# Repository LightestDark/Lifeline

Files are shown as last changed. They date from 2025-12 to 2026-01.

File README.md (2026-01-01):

# Lifeline

This project aims to expand on the existing LoRa Puck guide, to make a pair of fully functioning transmitters that can display messages from the latter via oled, provide accurate GPS location up to 2 meters and even vital info on moisture, temperature and pressure to make an esitmated guess on the weather at the area and relay it.

# Lessons

I LOVED the physics behind the why in the routing it actually linked so well to my own studies, especially the low pass filtering. Despite this being my smallest pcb to date by no means was it the easiest, with cramming as efficiently each component so there was enough room as well as keeping enough space to allow the RF components to work properly and juggle vias everywhere it was a labour.

# Assembly

Made a simple box with plently space for antennas and display







# PCB

Ensured short efficient tracks by precise placing of components





# Schematic

Added GPS, OLED and An array of sesnors packed into a BME280



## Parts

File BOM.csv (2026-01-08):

Index | LCSC# | MPN | Manufacturer | Package | Description | RoHS | Quantity | MOQ | Multiple | Unit Price($) | Extended Price($) | Product Link | Total Price ($)
1 | C92361 | CL05A474KA5NNNC | Samsung Electro-Mechanics | 402 | 25V 470nF X5R ±10% 0402 Ceramic Capacitors RoHS | yes | 10 | 10 | 10 | 0.0118 | 0.12 | https://www.lcsc.com/product-detail/C92361.html | 1.12
2 | C1525 | CL05B104KO5NNNC | Samsung Electro-Mechanics | 402 | 16V 100nF X7R ±10% 0402 Ceramic Capacitors RoHS | yes | 100 | 100 | 100 | 0.0012 | 0.12 | https://www.lcsc.com/product-detail/C1525.html | 1.24
3 | C1864241 | GJM1555C1H390GB01D | muRata | 402 | 50V 39pF C0G ±2% 0402 Ceramic Capacitors RoHS | yes | 20 | 20 | 20 | 0.0355 | 0.71 | https://www.lcsc.com/product-detail/C1864241.html | 1.95
4 | C76906 | GJM1555C1H3R3BB01D | muRata | 402 | 50V 3.3pF C0G 0402 Ceramic Capacitors RoHS | yes | 50 | 50 | 50 | 0.0166 | 0.83 | https://www.lcsc.com/product-detail/C76906.html | 1.78
5 | C77018 | GRM155R71H102KA01D | muRata | 402 | 50V 1nF X7R ±10% 0402 Ceramic Capacitors RoHS | yes | 100 | 100 | 100 | 0.002 | 0.2 | https://www.lcsc.com/product-detail/C77018.html | 1.98
6 | C76970 | GRM1555C1H470JA01D | muRata | 402 | 50V 47pF C0G ±5% 0402 Ceramic Capacitors RoHS | yes | 100 | 100 | 100 | 0.0022 | 0.22 | https://www.lcsc.com/product-detail/C76970.html | 2.2
7 | C307339 | CL05B473KB5VPNC | Samsung Electro-Mechanics | 402 | 50V 47nF X7R ±10% 0402 Ceramic Capacitors RoHS | yes | 100 | 100 | 100 | 0.0076 | 0.76 | https://www.lcsc.com/product-detail/C307339.html | 2.96
8 | C14445 | CL05A105KP5NNNC | Samsung Electro-Mechanics | 402 | 10V 1uF X5R ±10% 0402 Ceramic Capacitors RoHS | yes | 100 | 100 | 100 | 0.0017 | 0.17 | https://www.lcsc.com/product-detail/C14445.html | 4.13
9 | C76950 | GRM1555C1H150JA01D | muRata | 402 | 50V 15pF C0G ±5% 0402 Ceramic Capacitors RoHS | yes | 100 | 100 | 100 | 0.0025 | 0.25 | https://www.lcsc.com/product-detail/C76950.html | 4.38
10 | C315248 | CL05A106MP5NUNC | Samsung Electro-Mechanics | 402 | 10V 10uF X5R ±20% 0402 Ceramic Capacitors RoHS | yes | 20 | 20 | 20 | 0.0085 | 0.17 | https://www.lcsc.com/product-detail/C315248.html | 3.55
11 | C85815 | BLM15AX102SN1D | muRata | 402 | 490mΩ ±25% 1kΩ@100MHz 0402 Ferrite Beads and Chips RoHS | yes | 100 | 100 | 100 | 0.0055 | 0.55 | https://www.lcsc.com/product-detail/C85815.html | 4.1
12 | C5224443 | 0900FM15K0039E | Johanson Dielectrics | SMD-10P,1.2x2mm | SMD-10P,1.2x2mm Ceramic Filters RoHS | yes | 2 | 1 | 1 | 1.8851 | 3.77 | https://www.lcsc.com/product-detail/C5224443.html | 7.87
13 | C3025063 | USB4105-GF-A-060 | Global Connector Technology | SMD | SMD USB, DVI, HDMI Connector Assemblies RoHS | yes | 2 | 1 | 1 | 1.0013 | 2 | https://www.lcsc.com/product-detail/C3025063.html | 9.87
14 | C3221788 | LQW15DN150M00D | muRata | 402 | 15uH 100mA 0402 Fixed Inductors RoHS | yes | 2 | 1 | 1 | 1.1864 | 2.37 | https://www.lcsc.com/product-detail/C3221788.html | 12.24
15 | C337956 | LQW15AN9N1H00D | muRata | 402 | 9.1nH Unshielded Inductor 0402 Fixed Inductors RoHS | yes | 10 | 10 | 10 | 0.0388 | 0.39 | https://www.lcsc.com/product-detail/C337956.html | 12.63
16 | C22334 | LQW15AN47NG00D | muRata | 402 | 47nH Unshielded Inductor 0402 Fixed Inductors RoHS | yes | 20 | 20 | 20 | 0.0365 | 0.73 | https://www.lcsc.com/product-detail/C22334.html | 13.36
17 | C413063 | ERJ2RKF1000X | PANASONIC | 402 | 100mW 100Ω ±100ppm/℃ Thick Film Resistor ±1% 0402 Chip Resistor - Surface Mount RoHS | yes | 100 | 100 | 100 | 0.0047 | 0.47 | https://www.lcsc.com/product-detail/C413063.html | 13.83
18 | C191123 | ERJ2RKF1002X | PANASONIC | 402 | 100mW 10kΩ 50V ±100ppm/℃ Thick Film Resistor ±1% 0402 Chip Resistor - Surface Mount RoHS | yes | 100 | 100 | 100 | 0.0045 | 0.45 | https://www.lcsc.com/product-detail/C191123.html | 14.28
19 | C2076786 | ERJ2RKF27R4X | PANASONIC | 402 | 100mW 27.4Ω 50V ±100ppm/℃ Thick Film Resistor ±1% 0402 Chip Resistor - Surface Mount RoHS | yes | 50 | 50 | 50 | 0.0057 | 0.29 | https://www.lcsc.com/product-detail/C2076786.html | 14.57
20 | C242161 | ERJ2RKF1001X | PANASONIC | 402 | 100mW 1kΩ ±100ppm/℃ Thick Film Resistor ±1% 0402 Chip Resistor - Surface Mount RoHS | yes | 100 | 100 | 100 | 0.0049 | 0.49 | https://www.lcsc.com/product-detail/C242161.html | 15.06
21 | C105872 | RC0402FR-075K1L | YAGEO | 402 | 5.1kΩ 62.5mW 50V ±100ppm/℃ Thick Film Resistor ±1% 0402 Chip Resistor - Surface Mount RoHS | yes | 100 | 100 | 100 | 0.0007 | 0.07 | https://www.lcsc.com/product-detail/C105872.html | 15.13
22 | C2689642 | PTS636SK25SMTRLFS | C&K | SMD,6x3.5mm | 12V Rectangular Button SPST-NO 50mA SMD,6x3.5mm Tactile Switches RoHS | yes | 5 | 5 | 5 | 0.3601 | 1.8 | https://www.lcsc.com/product-detail/C2689642.html | 16.93
23 | C191341 | SX1262IMLTRT | SEMTECH | QFN-24-EP(4x4) | 300Kbps General Purpose ISM <1 GHz SPI -148dBm 150MHz~960MHz QFN-24-EP(4x4) RF Transceiver ICs RoHS | yes | 1 | 1 | 1 | 3.1633 | 3.16 | https://www.lcsc.com/product-detail/C191341.html | 20.09
24 | C2040 | RP2040 | Raspberry Pi | LQFN-56(7x7) | 133MHz 30 LQFN-56(7x7) Microcontrollers RoHS | yes | 1 | 1 | 1 | 0.9482 | 0.95 | https://www.lcsc.com/product-detail/C2040.html | 21.04
25 | C97521 | W25Q128JVSIQ | Winbond | SOIC-8-208mil | 128Mbit 2.7V~3.6V 133MHz SPI SOIC-8-208mil Memory (ICs) RoHS | yes | 1 | 1 | 1 | 1.8032 | 1.8 | https://www.lcsc.com/product-detail/C97521.html | 22.84
26 | C51118 | AP2112K-3.3TRG1 | DIODES | SOT-25-5 | 65dB@(1kHz) Positive Fixed 3.3V SOT-25-5 Voltage Regulators - Linear, Low Drop Out (LDO) Regulators RoHS | yes | 5 | 5 | 5 | 0.1344 | 0.67 | https://www.lcsc.com/product-detail/C51118.html | 23.51
27 | C470892 | PE4259-63 | pSemi | SC-70-6 | 30dB 0.35dB SC-70-6 RF Switches RoHS | yes | 1 | 1 | 1 | 0.5777 | 0.58 | https://www.lcsc.com/product-detail/C470892.html | 24.09
28 | C276421 | ABM8G-12.000MHZ-B4Y-T | ABRACON | SMD3225-4P | 10pF SMD3225-4P Crystals RoHS | yes | 2 | 1 | 1 | 0.454 | 0.91 | https://www.lcsc.com/product-detail/C276421.html | 25
29 | C5187559 | ABM8G-32.000MHZ-B4Y-T | ABRACON | SMD3225-4P | SMD3225-4P Crystals RoHS | yes | 2 | 1 | 1 | 0.7108 | 1.42 | https://www.lcsc.com/product-detail/C5187559.html | 26.42
30 | N/A | Shipping global direct |  |  |  |  |  |  |  |  | 9.13 |  | 35.55
31 | N/A | JLCPCB excl shipping |  |  | green+stencil |  |  |  |  |  | 14.08 |  | 49.63
32 |  | Shipping europacket bc cheaper than standard direct |  |  | 1 eur cheaper approx |  |  |  |  |  | 24.36 |  | 69.99
33 |  | 4pin Headers |  |  |  |  |  |  |  |  |  |  | 4
33 |  | 3D printing form printing legion delivery |  |  | Royal Mail |  |  |  |  |  | 10.00
34 |  | Customs |  |  |  |  |  |  |  |  | 8.3 |  | TOTAL: 97.40

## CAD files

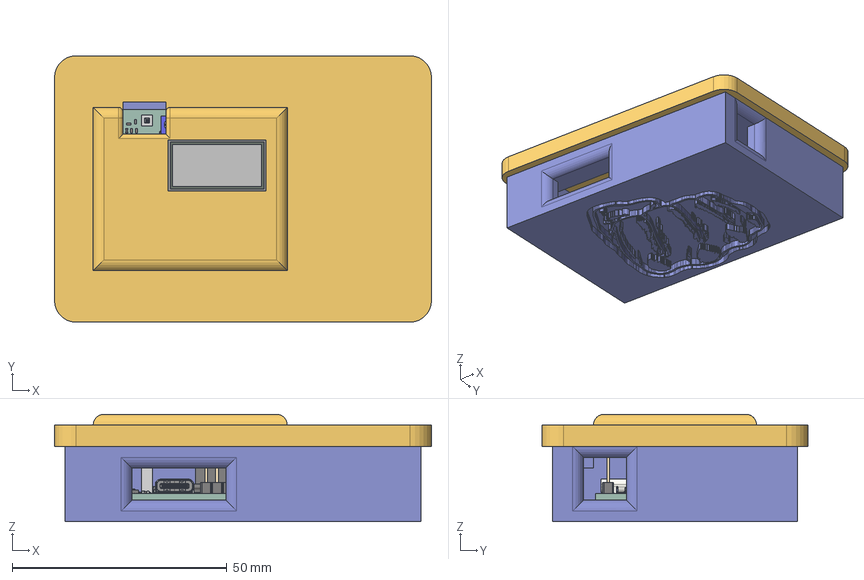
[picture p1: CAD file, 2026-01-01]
Lifeline.step
87.7 x 62.0 x 25.0 mm
C_0402_1005Metric x 25
PinSocket_1x01_P2.54mm_Vertical
QFN-56-1EP_7x7mm_P0.4mm_EP3.2x3.2mm
R_0402_1005Metric x 8
SOIC-8_5.3x5.3mm_P1.27mm
lorapuck 1.9.1
lorapuck 1.9.2
lorapuck 1.9.3
SW_Tactile_SPST_NO_Straight_CK_PTS636Sx25SMTRLFS x 2
QFN-24-1EP_4x4mm_P0.5mm_EP2.6x2.6mm
Crystal_SMD_Abracon_ABM8G-4Pin_3.2x2.5mm
PinSocket_1x04_P2.54mm_Vertical
SOT-363_SC-70-6
L_0402_1005Metric x 4
PinHeader_1x04_P2.54mm_Vertical x 2
USB_C_Receptacle_GCT_USB4105-xx-A_16P_TopMnt_Horizontal
SOT-23-5
Crystal_SMD_3225-4Pin_3.2x2.5mm
lorapuck_PCB
DM-OLED096-636_Panel
DM-OLED096-636_Module

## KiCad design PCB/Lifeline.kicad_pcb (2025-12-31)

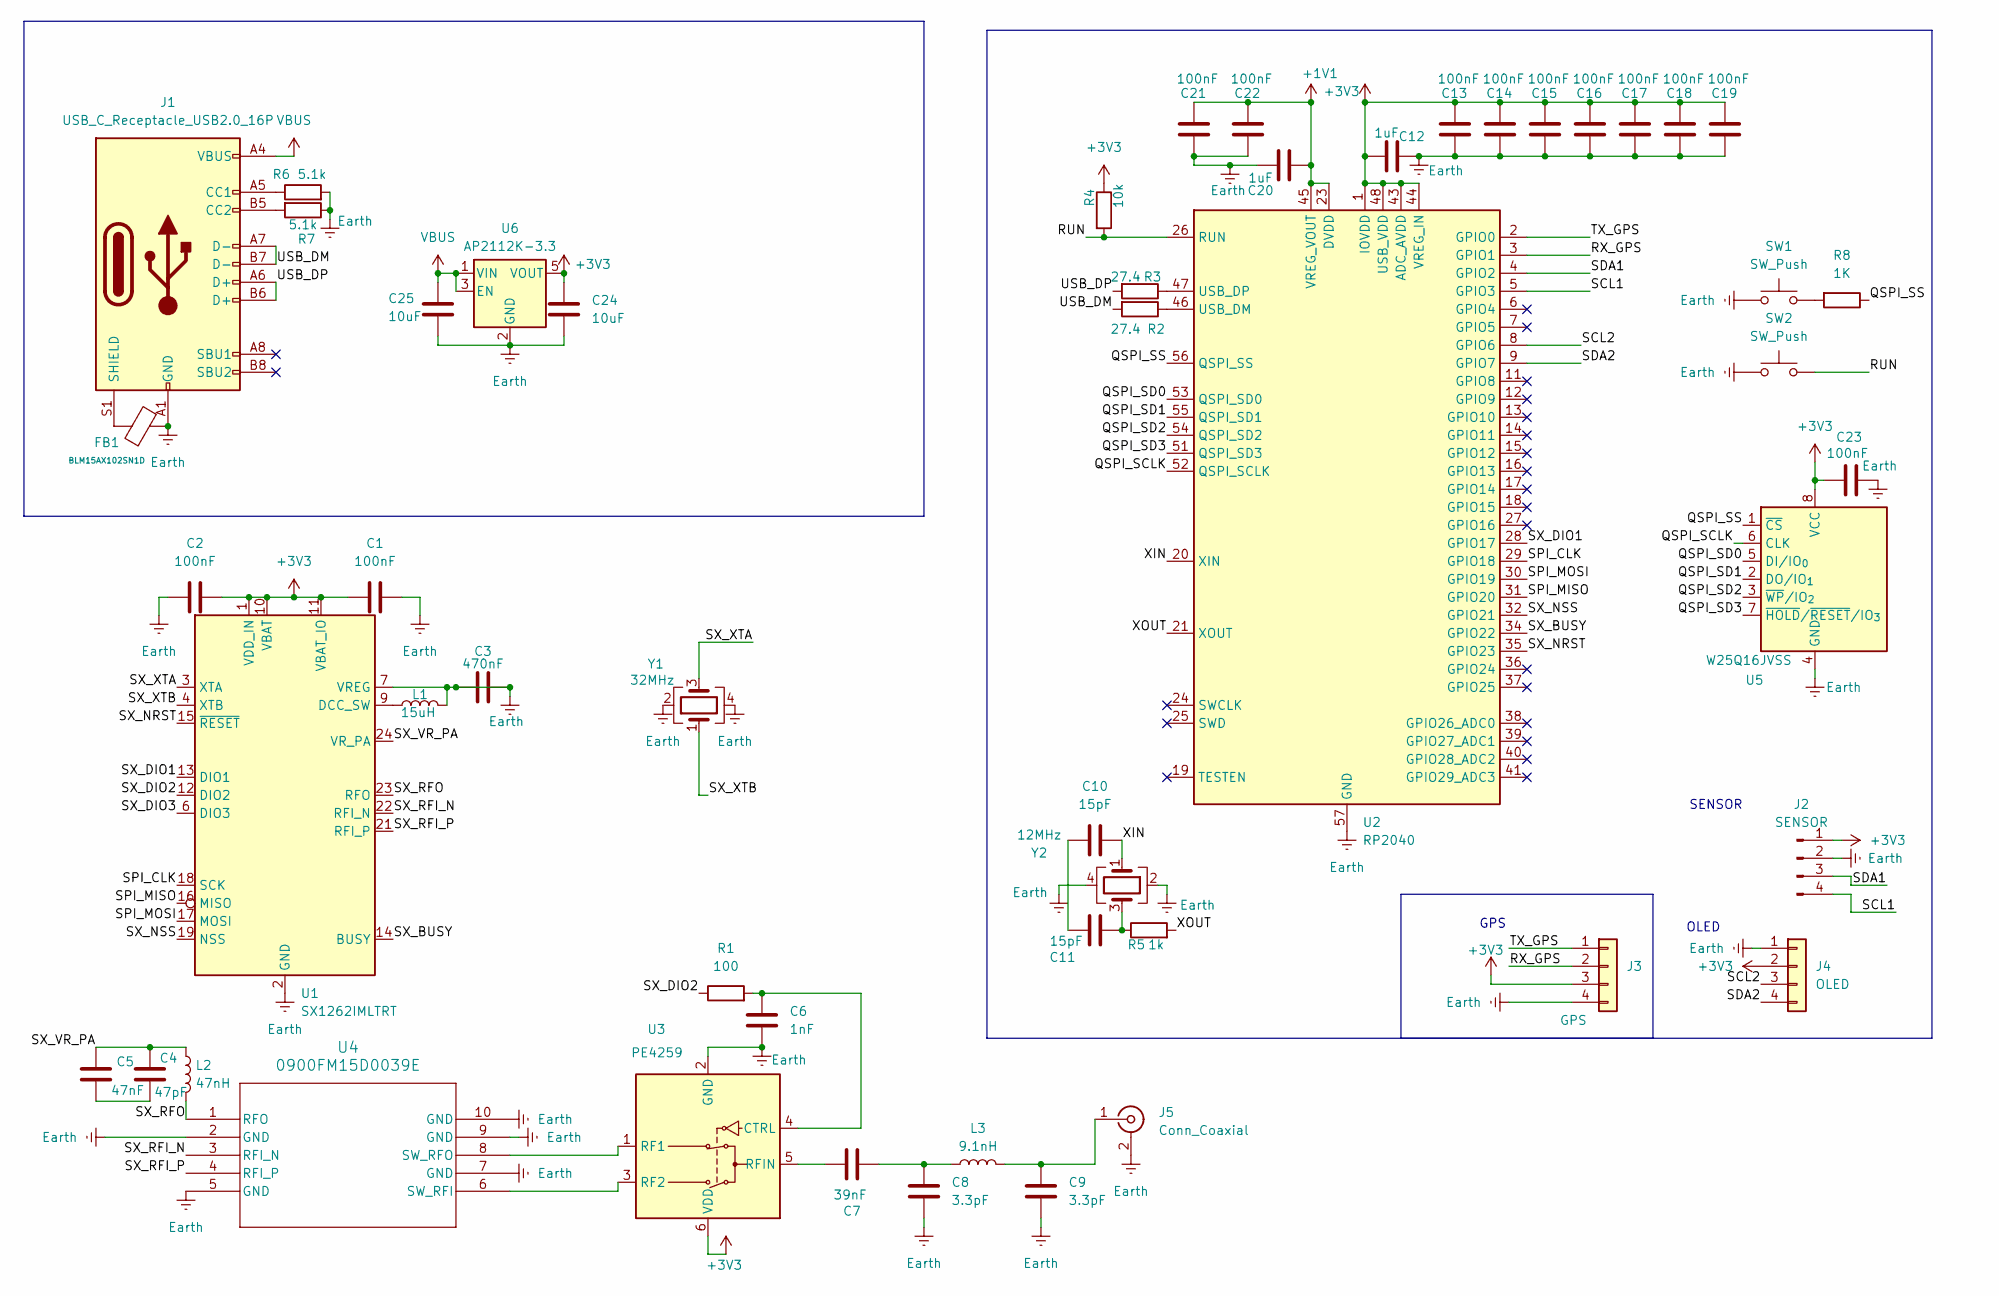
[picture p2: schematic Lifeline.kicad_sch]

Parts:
C1, C2, C13, C14, C15, C16, C17, C18, C19, C21, C22, C23: 100nF; C_0402_1005Metric
C3: 470nF; C_0402_1005Metric
C4: 47pF; C_0402_1005Metric
C5: 47nF; C_0402_1005Metric
C6: 1nF; C_0402_1005Metric
C7: 39nF; C_0402_1005Metric
C8, C9: 3.3pF; C_0402_1005Metric
C10, C11: 15pF; C_0402_1005Metric
C12, C20: 1uF; C_0402_1005Metric
C24, C25: 10uF; C_0402_1005Metric
FB1: BLM15AX102SN1D; L_0402_1005Metric; Current Rating 2A; Tolerance ±25%; Part BLM18PG121SN1D; LCSC C14709
J1: USB_C_Receptacle_USB2.0_16P; USB_C_Receptacle_GCT_USB4105-xx-A_16P_TopMnt_Horizontal
J2: SENSOR; PinHeader_1x04_P2.54mm_Vertical
J3: GPS; PinHeader_1x04_P2.54mm_Vertical
J4: OLED; PinSocket_1x04_P2.54mm_Vertical
J5: Conn_Coaxial; U.FL_Hirose_U.FL-R-SMT-1_Vertical
L1: 15uH; L_0402_1005Metric
L2: 47nH; L_0402_1005Metric
L3: 9.1nH; L_0402_1005Metric
R1: 100; R_0402_1005Metric
R2, R3: 27.4; R_0402_1005Metric
R4: 10k; R_0402_1005Metric
R5: 1k; R_0402_1005Metric
R6, R7: 5.1k; R_0402_1005Metric
R8: 1K; R_0402_1005Metric
SW1, SW2: SW_Push; SW_Tactile_SPST_NO_Straight_CK_PTS636Sx25SMTRLFS
U1: SX1262IMLTRT; QFN-24-1EP_4x4mm_P0.5mm_EP2.6x2.6mm
U2: RP2040; QFN-56-1EP_7x7mm_P0.4mm_EP3.2x3.2mm
U3: PE4259; SOT-363_SC-70-6
U4: 0900FM15D0039E; Balun_Johanson_0900FM15K0039
U5: W25Q16JVSS; SOIC-8_5.3x5.3mm_P1.27mm
U6: AP2112K-3.3; SOT-23-5
Y1: 32MHz; Crystal_SMD_3225-4Pin_3.2x2.5mm
Y2: 12MHz; Crystal_SMD_Abracon_ABM8G-4Pin_3.2x2.5mm

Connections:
+1V1: C20.2, C21.1, C22.1, U2.23 (DVDD), U2.45 (VREG_VOUT), U2.50 (DVDD)
+3V3: C1.1, C2.2, C12.1, C13.1, C14.1, C15.1, C16.1, C17.1, C18.1, C19.1, C23.1, C24.1, J2.1, J3.3, J4.2, R4.1, U1.1 (VDD_IN), U1.10 (VBAT), U1.11 (VBAT_IO), U2.1 (IOVDD), U2.10 (IOVDD), U2.22 (IOVDD), U2.33 (IOVDD), U2.42 (IOVDD), U2.43 (ADC_AVDD), U2.44 (VREG_IN), U2.48 (USB_VDD), U2.49 (IOVDD), U3.6 (VDD), U5.8 (VCC), U6.5 (VOUT)
/QSPI_SCLK: U2.52 (QSPI_SCLK), U5.6 (CLK)
/QSPI_SD0: U2.53 (QSPI_SD0), U5.5 (DI/IO_{0})
/QSPI_SD1: U2.55 (QSPI_SD1), U5.2 (DO/IO_{1})
/QSPI_SD2: U2.54 (QSPI_SD2), U5.3 (~WP/IO_{2})
/QSPI_SD3: U2.51 (QSPI_SD3), U5.7 (~HOLD/~RESET/IO_{3})
/QSPI_SS: R8.1, U2.56 (QSPI_SS), U5.1 (~CS)
/RUN: R4.2, SW2.2, U2.26 (RUN)
/RX_GPS: J3.2, U2.3 (GPIO1)
/SCL1: J2.4, U2.5 (GPIO3)
/SCL2: J4.3, U2.8 (GPIO6)
/SDA1: J2.3, U2.4 (GPIO2)
/SDA2: J4.4, U2.9 (GPIO7)
/SPI_CLK: U1.18 (SCK), U2.29 (GPIO18)
/SPI_MISO: U1.16 (MISO), U2.31 (GPIO20)
/SPI_MOSI: U1.17 (MOSI), U2.30 (GPIO19)
/SX_BUSY: U1.14 (BUSY), U2.34 (GPIO22)
/SX_DIO1: U1.13 (DIO1), U2.28 (GPIO17)
/SX_DIO2: R1.1, U1.12 (DIO2)
/SX_DIO3: U1.6 (DIO3)
/SX_NRST: U1.15 (~RESET), U2.35 (GPIO23)
/SX_NSS: U1.19 (NSS), U2.32 (GPIO21)
/SX_RFI_N: U1.22 (RFI_N), U4.3 (RFI_N)
/SX_RFI_P: U1.21 (RFI_P), U4.4 (RFI_P)
/SX_RFO: L2.2, U1.23 (RFO), U4.1 (RFO)
/SX_VR_PA: C4.1, C5.1, L2.1, U1.24 (VR_PA)
/SX_XTA: U1.3 (XTA), Y1.3
/SX_XTB: U1.4 (XTB), Y1.1
/TX_GPS: J3.1, U2.2 (GPIO0)
/USB_DM: J1.A7 (D-), J1.B7 (D-), R2.2
/USB_DP: J1.A6 (D+), J1.B6 (D+), R3.2
/XIN: C10.2, U2.20 (XIN), Y2.1
/XOUT: R5.2, U2.21 (XOUT)
Earth: C1.2, C2.1, C3.1, C3.2, C6.2, C8.2, C9.2, C12.2, C13.2, C14.2, C15.2, C16.2, C17.2, C18.2, C19.2, C20.1, C21.2, C22.2, C23.2, C24.2, C25.2, FB1.2, J1.A1 (GND), J1.A12 (GND), J1.B1 (GND), J1.B12 (GND), J2.2, J3.4, J4.1, J5.2 (Ext), L1.2, R6.2, R7.1, SW1.1, SW2.1, U1.2 (GND), U1.5 (GND), U1.7 (VREG), U1.8 (GND), U1.20 (GND), U1.25 (GND), U2.57 (GND), U3.2 (GND), U4.2 (GND), U4.5 (GND), U4.7 (GND), U4.9 (GND), U4.10 (GND), U5.4 (GND), U6.2 (GND), Y1.2, Y1.4, Y2.2, Y2.4
unnamed: C4.2, C5.2
unnamed: C7.2, C8.1, L3.1
unnamed: C10.1, C11.1
unnamed: C11.2, R5.1, Y2.3
unnamed: J1.A5 (CC1), R6.1
unnamed: J1.B5 (CC2), R7.2
unnamed: FB1.1, J1.S1 (SHIELD)
unnamed: C9.1, J5.1 (In), L3.2
unnamed: R8.2, SW1.2
unnamed: L1.1, U1.9 (DCC_SW)
unnamed: R2.1, U2.46 (USB_DM)
unnamed: R3.1, U2.47 (USB_DP)
unnamed: C6.1, R1.2, U3.4 (CTRL)
unnamed: U3.1 (RF1), U4.8 (SW_RFO)
unnamed: U3.3 (RF2), U4.6 (SW_RFI)
unnamed: C7.1, U3.5 (RFIN)
VBUS: C25.1, J1.A4 (VBUS), J1.A9 (VBUS), J1.B4 (VBUS), J1.B9 (VBUS), U6.1 (VIN), U6.3 (EN)

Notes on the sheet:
GPS
OLED
SENSOR

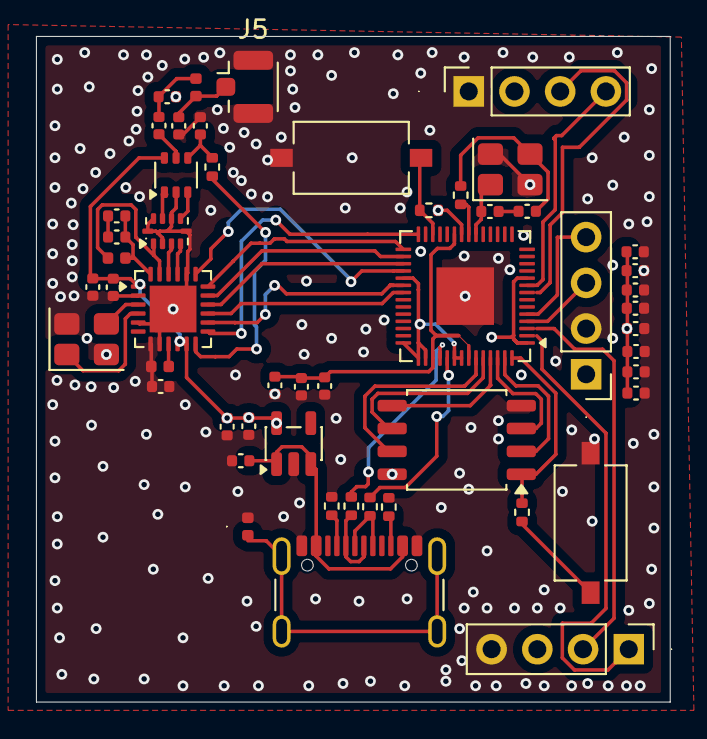
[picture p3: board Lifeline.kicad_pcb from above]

Board: 4 copper layers, 35.2 x 37.0 mm, 52 parts (0 on the bottom side), 51 nets.
